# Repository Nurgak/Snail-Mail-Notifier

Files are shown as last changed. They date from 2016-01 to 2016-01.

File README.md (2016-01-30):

# Snail Mail Notifier

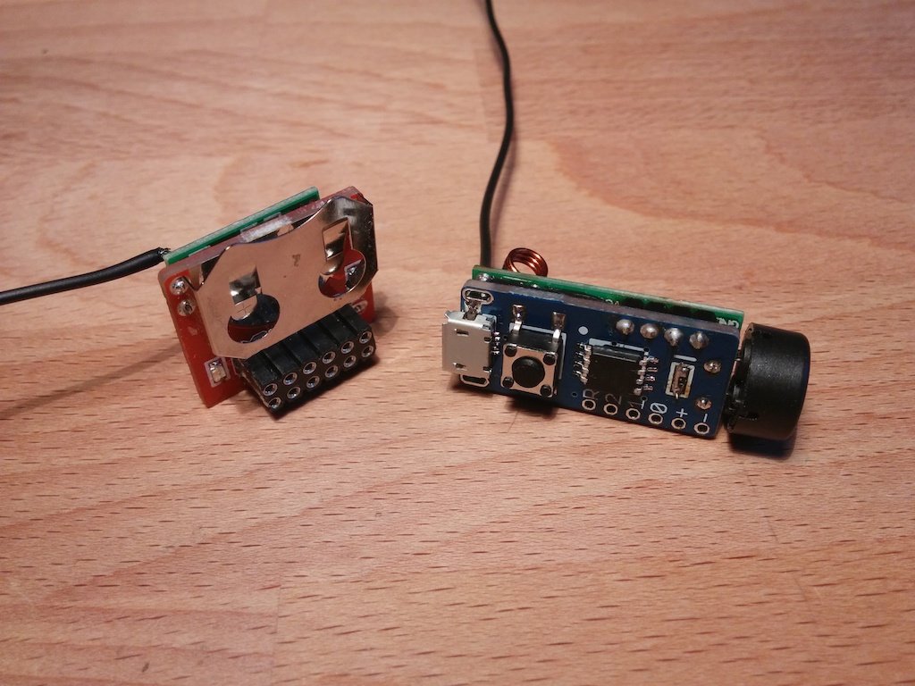
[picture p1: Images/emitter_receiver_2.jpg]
Snail Mail Notifier transmitter and receiver


The Snail Mail Notifier is a small module based on a one-way transmitter-receiver pair and [ATtiny85](http://www.atmel.com/devices/attiny85.aspx) microcontrollers, it's purpose is to inform a user of the arrival of regular mail as soon as the mailbox lid has been opened. The receiver can notify the user via a buzzer, a blinking LED or transmit data to a computer that can forward an e-mail.

[The project development is documented on Hackaday.io](https://hackaday.io/project/1954-snail-mail-notifier).

## License

The Snail Mail Notifier is published under [Creative Commons Attribution license](http://creativecommons.org/licenses/by/3.0/).



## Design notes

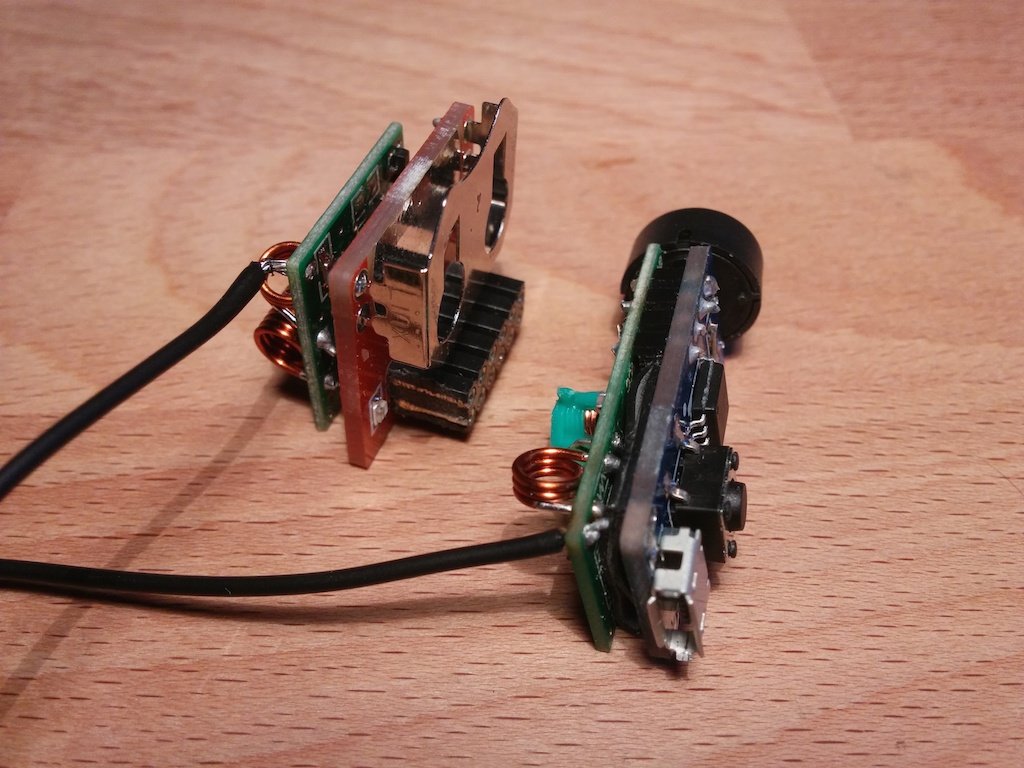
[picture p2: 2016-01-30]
Images/emitter_receiver.jpg

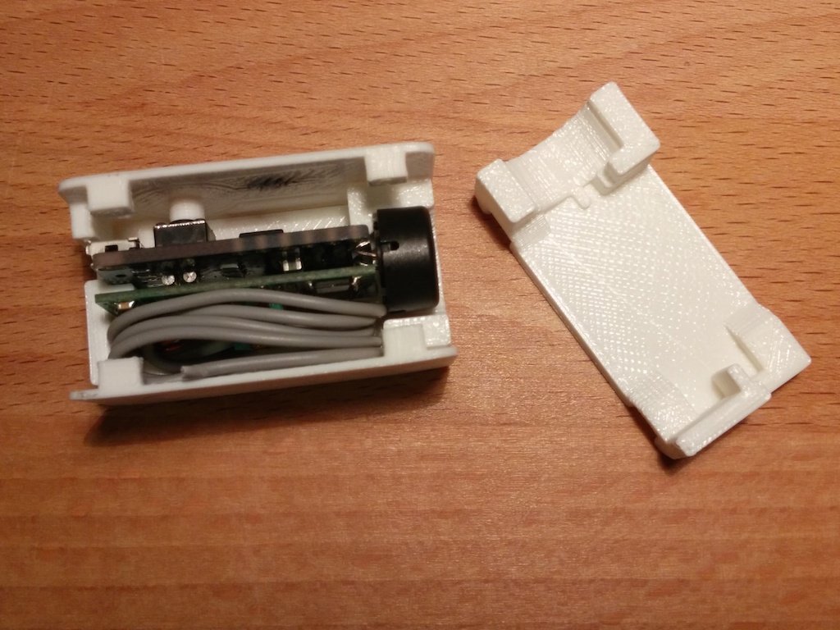
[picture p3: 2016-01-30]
Images/receiver_opened.jpg

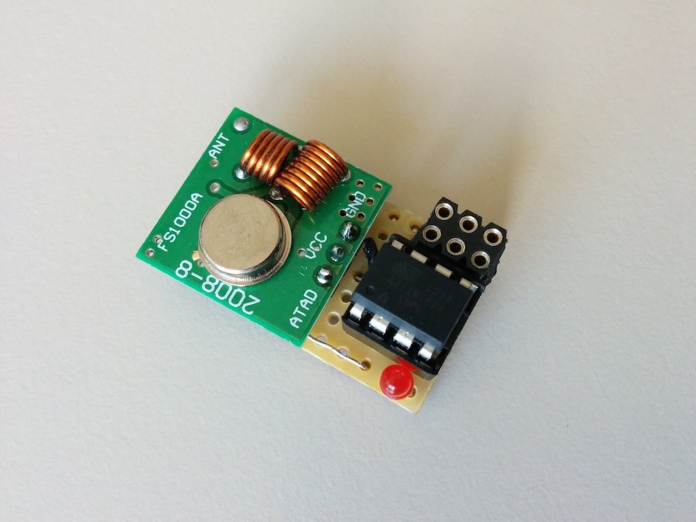
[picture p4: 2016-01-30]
Images/emitter_perfboard.jpg

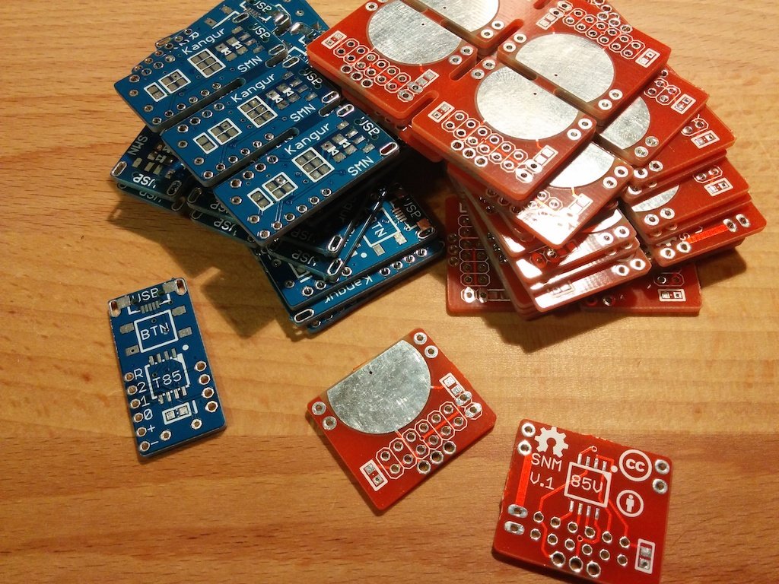
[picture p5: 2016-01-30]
Images/pcbs_panelised.jpg

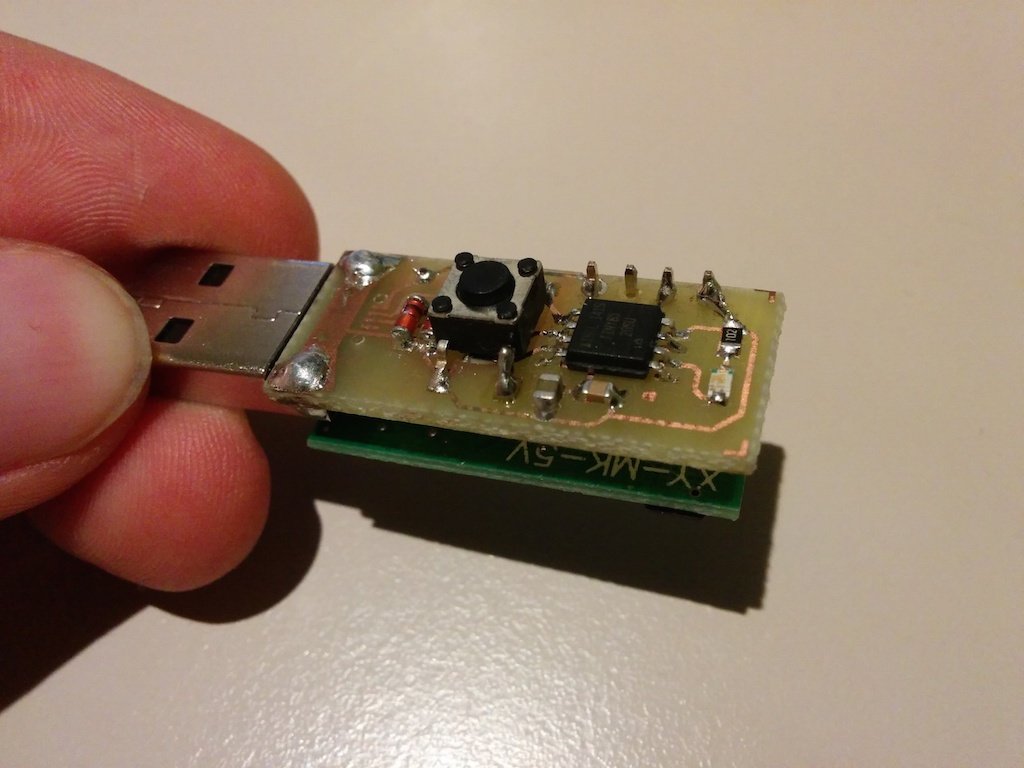
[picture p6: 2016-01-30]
Images/receiver_etched.jpg

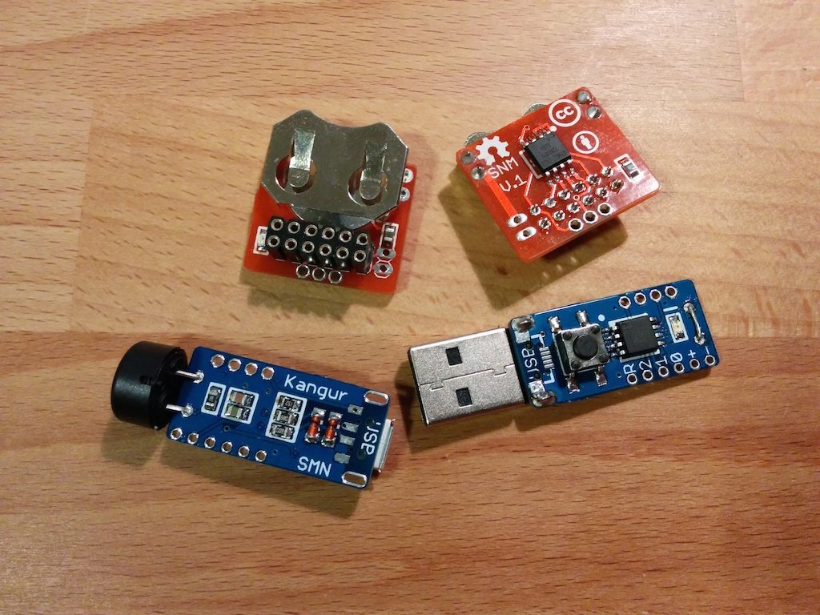
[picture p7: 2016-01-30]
Images/emitter_receiver_3.jpg

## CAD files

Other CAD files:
Hardware/Enclosure_receiver.skp

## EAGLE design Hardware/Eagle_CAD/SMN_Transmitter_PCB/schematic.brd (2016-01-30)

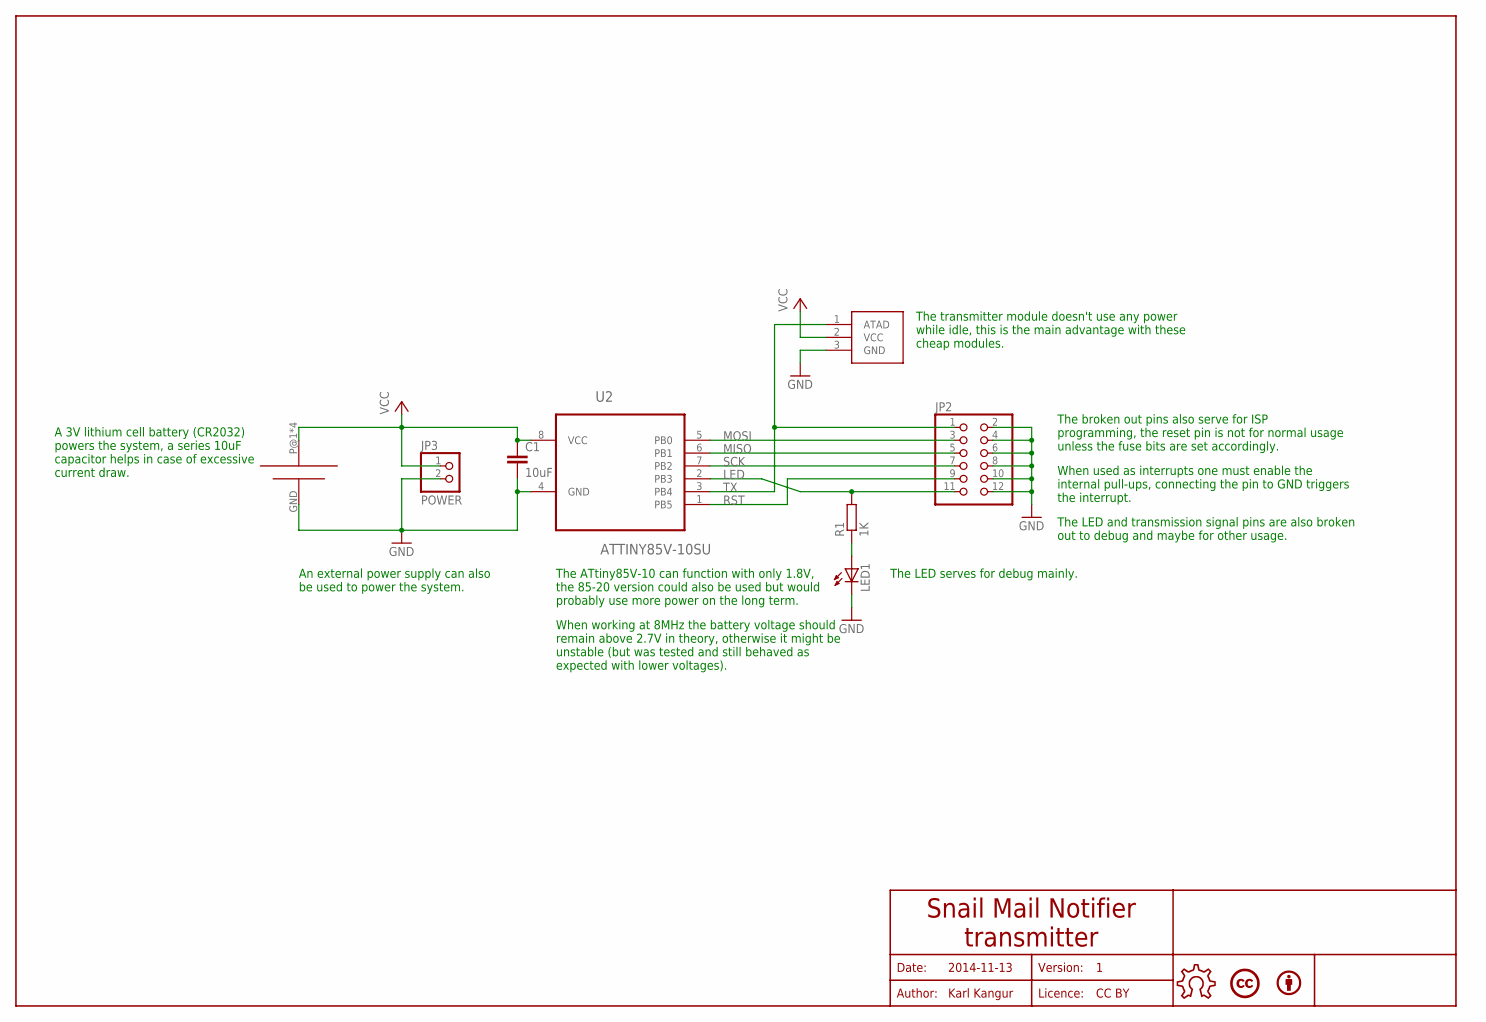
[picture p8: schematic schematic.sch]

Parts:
BY1: BYBOTTOM; BY
C1: 10uF; C0805
JP2: PINHD-2X6; 2X06
JP3: POWER; 1X02
LED1: LEDCHIPLED_0805; CHIPLED_0805
LICENCE1: LICENCECC-BOTTOM; CREATIVE-COMMONS
R1: 1K; R0805
U2: ATTINY85V-10SU; SOIC127P798X216-8N
U$1: RF_LINK_TRANSMITTER
U$2: CR2032-BATTERY-HOLDER; CR2032-BATTERY-HOLDER-PCB
U$5: OPEN-HARDWARE-LOGOBOTTOM-SMALL; OPEN-HARDWARE-BOTTOM-SMALL

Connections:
GND: C1.2, JP2.2, JP2.4, JP2.6, JP2.8, JP2.10, JP2.12, JP3.2, LED1.C, U2.4 (GND), U$1.3 (GND), U$2.GND (N)
LED: JP2.11, R1.2, U2.2 (PB3)
MISO: JP2.5, U2.6 (PB1)
MOSI: JP2.3, U2.5 (PB0)
unnamed: LED1.A, R1.1
RST: JP2.9, U2.1 (PB5)
SCK: JP2.7, U2.7 (PB2)
TX: JP2.1, U2.3 (PB4), U$1.1 (ATAD)
VCC: C1.1, JP3.1, U2.8 (VCC), U$1.2 (VCC), U$2.P@1, U$2.P@2, U$2.P@3, U$2.P@4

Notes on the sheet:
Date:
Author:
Licence:
Version:
2014-11-13
Karl Kangur
CC BY
Snail Mail Notifier transmitter
The ATtiny85V-10 can function with only 1.8V, the 85-20 version could also be used but would probably use more power on the long term.
The broken out pins also serve for ISP programming, the reset pin is not for normal usage unless the fuse bits are set accordingly.
A 3V lithium cell battery (CR2032) powers the system, a series 10uF capacitor helps in case of excessive current draw.
An external power supply can also be used to power the system.
The transmitter module doesn't use any power while idle, this is the main advantage with these cheap modules.
When used as interrupts one must enable the internal pull-ups, connecting the pin to GND triggers the interrupt.
The LED serves for debug mainly.
When working at 8MHz the battery voltage should remain above 2.7V in theory, otherwise it might be unstable (but was tested and still behaved as expected with lower voltages).
The LED and transmission signal pins are also broken out to debug and maybe for other usage.

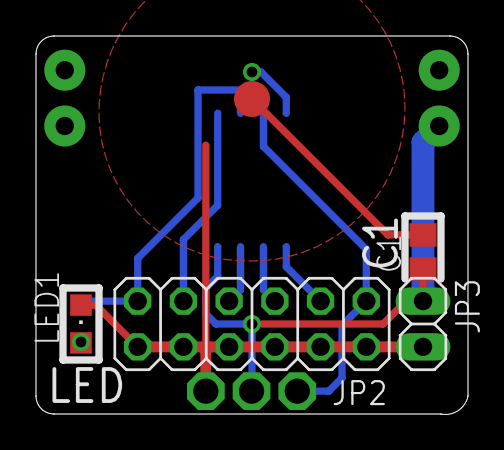
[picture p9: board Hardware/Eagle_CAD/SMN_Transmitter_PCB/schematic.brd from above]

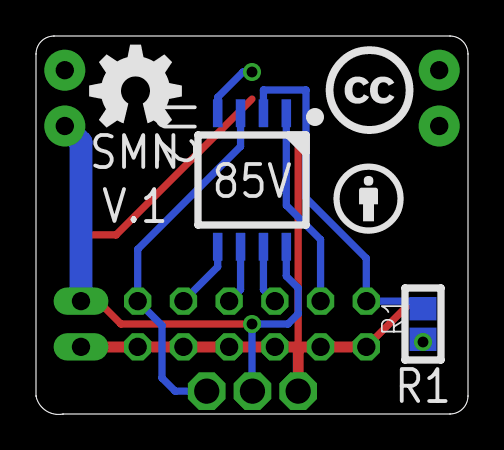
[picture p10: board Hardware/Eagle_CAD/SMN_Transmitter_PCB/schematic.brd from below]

Board: 2 copper layers, 24.0 x 21.0 mm, 11 parts (3 on the bottom side), 9 nets.

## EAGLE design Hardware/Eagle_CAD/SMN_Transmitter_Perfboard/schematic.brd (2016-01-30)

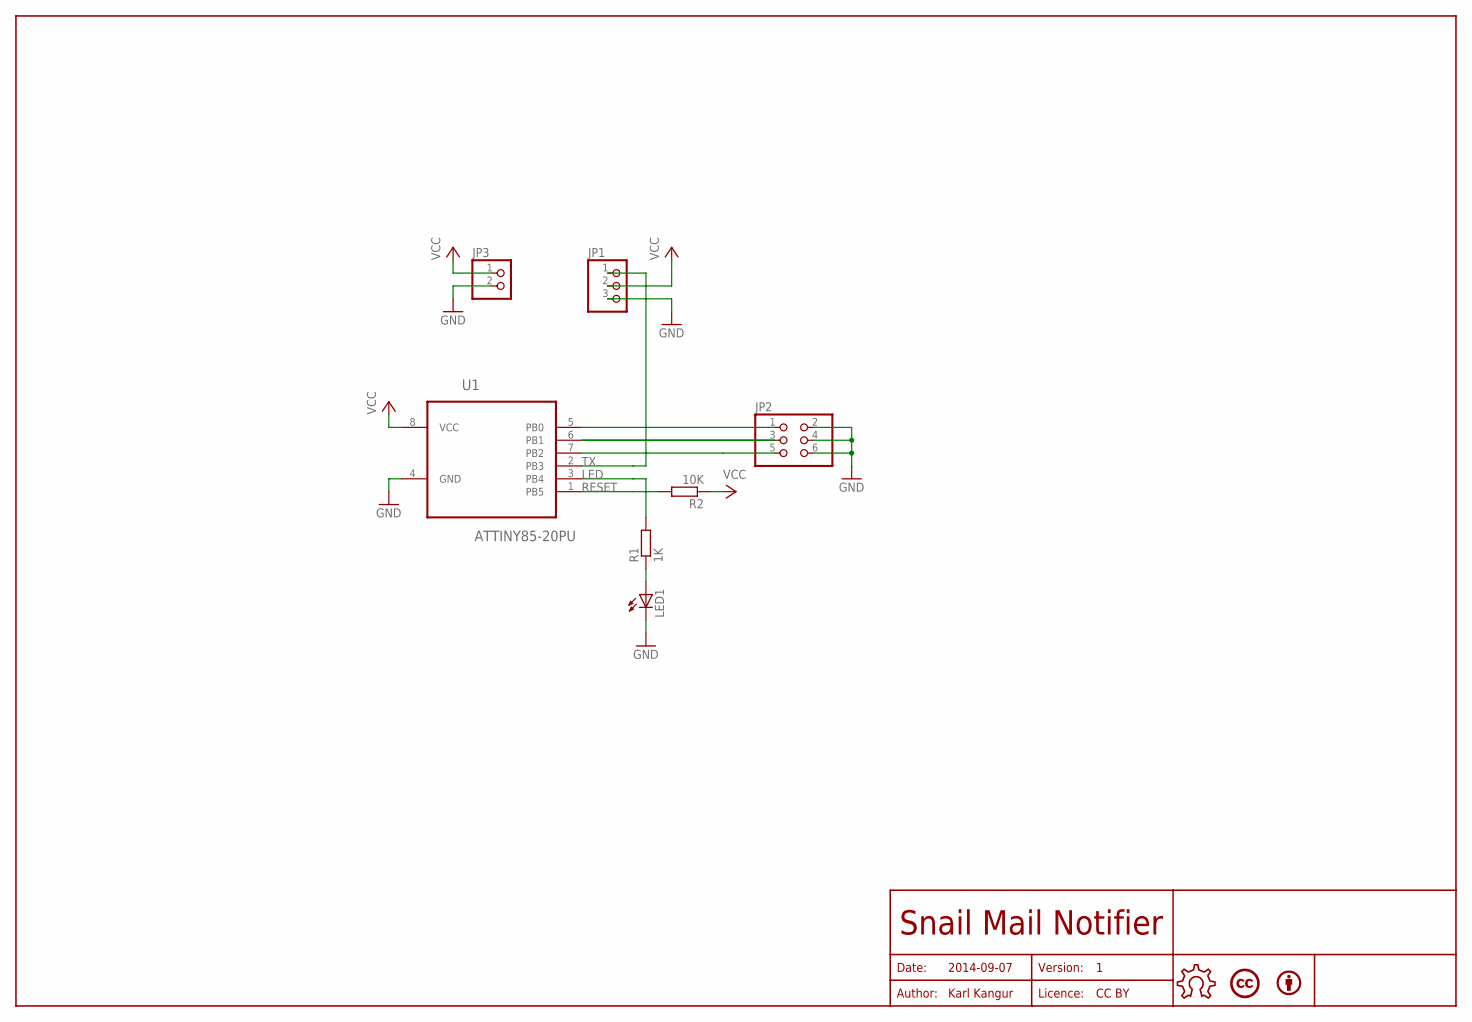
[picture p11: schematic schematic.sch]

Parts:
BY1: BYBOTTOM; BY
JP1: PINHD-1X3; 1X03
JP2: PINHD-2X3; 2X03
JP3: PINHD-1X2/90; 1X02/90
LED1: LED3MM
LICENCE1: LICENCECC-BOTTOM; CREATIVE-COMMONS
R1: 1K; R0805
R2: 10K; R0805
U1: ATTINY85-20PU; DIP254P762X533-8
U$5: OPEN-HARDWARE-LOGOBOTTOM-SMALL; OPEN-HARDWARE-BOTTOM-SMALL

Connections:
GND: JP1.3, JP2.2, JP2.4, JP2.6, JP3.2, LED1.K (C)
LED: R1.2, U1.3 (PB4)
unnamed: LED1.A, R1.1
unnamed: JP2.1, U1.5 (PB0)
unnamed: JP2.3, U1.6 (PB1)
unnamed: JP2.5, U1.7 (PB2)
RESET: R2.2, U1.1 (PB5)
TX: JP1.1, U1.2 (PB3)
VCC: JP1.2, JP3.1, R2.1, U1.8 (VCC)

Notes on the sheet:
Date:
Author:
Licence:
Version:
2014-09-07
Karl Kangur
CC BY
Snail Mail Notifier

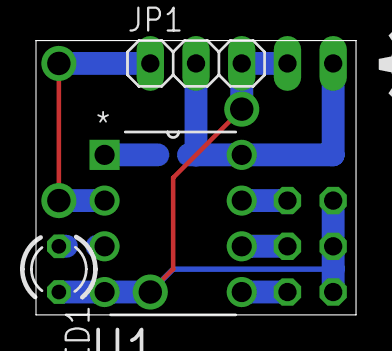
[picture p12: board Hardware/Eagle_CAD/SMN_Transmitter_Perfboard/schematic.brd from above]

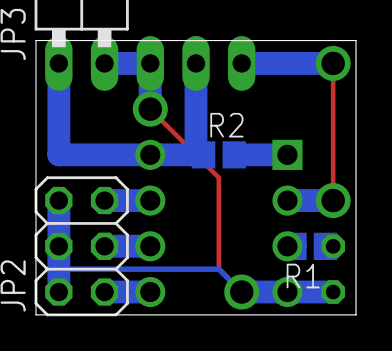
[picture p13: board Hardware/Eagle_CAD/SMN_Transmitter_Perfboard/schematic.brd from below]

Board: 2 copper layers, 17.8 x 15.2 mm, 10 parts (7 on the bottom side), 9 nets.

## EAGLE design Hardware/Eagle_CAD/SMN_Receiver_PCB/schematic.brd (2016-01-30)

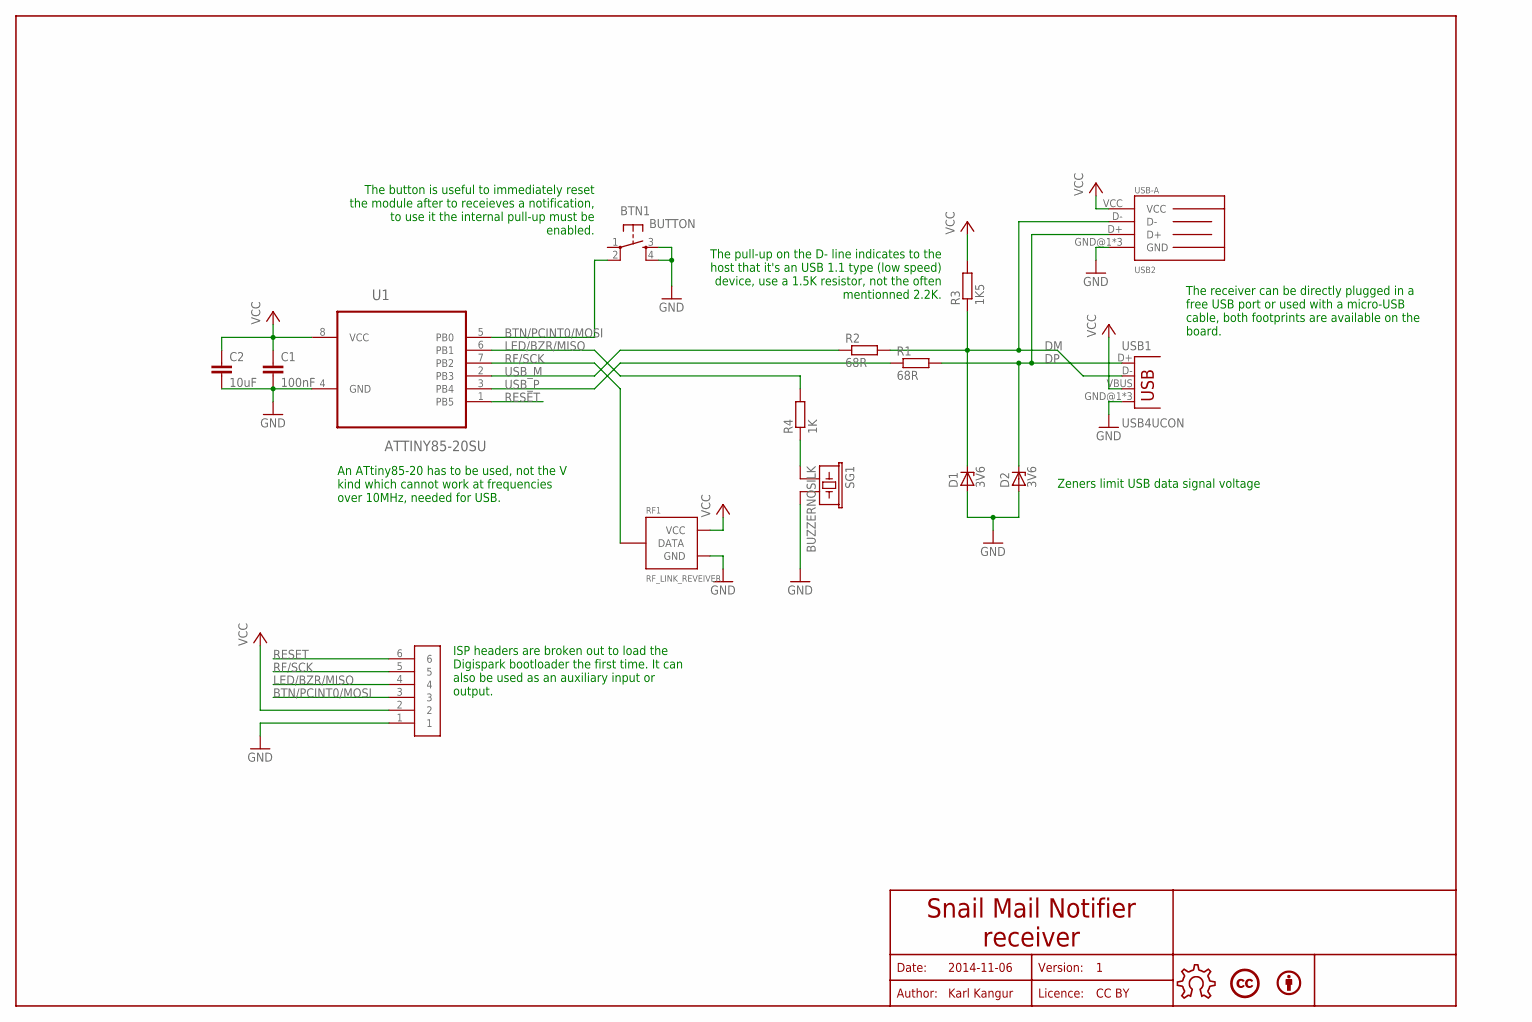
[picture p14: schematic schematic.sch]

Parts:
BTN1: BUTTON
BY1: BYBOTTOM; BY
C1: 100nF; C0805
C2: 10uF; C0805
D1, D2: 3V6; SOD80C
LICENCE1: LICENCECC-BOTTOM; CREATIVE-COMMONS
PIN1: PINS-6
R1, R2: 68R; R0805
R3: 1K5; R0805
R4: 1K; R0805
RF1: RF_LINK_REVEIVER
SG1: BUZZERNOSILK; PS1240P02BT-NOSILK
U1: ATTINY85-20SU; SOIC127P798X216-8N
U$5: OPEN-HARDWARE-LOGOBOTTOM-SMALL; OPEN-HARDWARE-BOTTOM-SMALL
USB1: USB4UCON; USB-MICROB-4UCON
USB2: USB-A

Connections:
BTN/PCINT0/MOSI: BTN1.2, PIN1.3, U1.5 (PB0)
DM: D1.C, R2.2, R3.1, USB1.D-, USB2.D-
DP: D2.C, R1.2, USB1.D+, USB2.D+
GND: BTN1.3, BTN1.4, C1.2, C2.2, D1.A, D2.A, PIN1.1, RF1.GND, SG1.P$2 (2), U1.4 (GND), USB1.GND@1 (GND), USB1.GND@4 (GND), USB1.GND@5 (GND), USB2.GND@1 (GND), USB2.GND@2 (GND), USB2.GND@3 (GND)
LED/BZR/MISO: PIN1.4, R4.2, U1.6 (PB1)
unnamed: R4.1, SG1.P$1 (1)
RESET: PIN1.6, U1.1 (PB5)
RF/SCK: PIN1.5, RF1.DATA@1 (DATA), RF1.DATA@2 (DATA), U1.7 (PB2)
USB_M: R2.1, U1.2 (PB3)
USB_P: R1.1, U1.3 (PB4)
VCC: C1.1, C2.1, PIN1.2, R3.2, RF1.VCC, U1.8 (VCC), USB1.VBUS, USB2.VCC

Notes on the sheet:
Date:
Author:
Licence:
Version:
2014-11-06
Karl Kangur
CC BY
Snail Mail Notifier receiver
The receiver can be directly plugged in a free USB port or used with a micro-USB cable, both footprints are available on the board.
Zeners limit USB data signal voltage
The pull-up on the D- line indicates to the host that it's an USB 1.1 type (low speed) device, use a 1.5K resistor, not the often mentionned 2.2K.
The button is useful to immediately reset the module after to receieves a notification, to use it the internal pull-up must be enabled.
An ATtiny85-20 has to be used, not the V kind which cannot work at frequencies over 10MHz, needed for USB.
ISP headers are broken out to load the Digispark bootloader the first time. It can also be used as an auxiliary input or output.

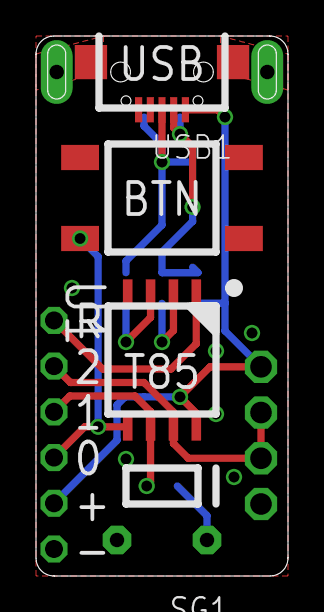
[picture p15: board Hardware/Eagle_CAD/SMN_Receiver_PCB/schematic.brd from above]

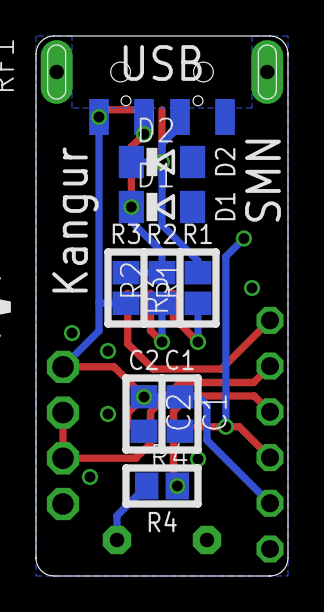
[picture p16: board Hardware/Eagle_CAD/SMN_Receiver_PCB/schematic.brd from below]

Board: 2 copper layers, 14.0 x 30.0 mm, 18 parts (12 on the bottom side), 11 nets.

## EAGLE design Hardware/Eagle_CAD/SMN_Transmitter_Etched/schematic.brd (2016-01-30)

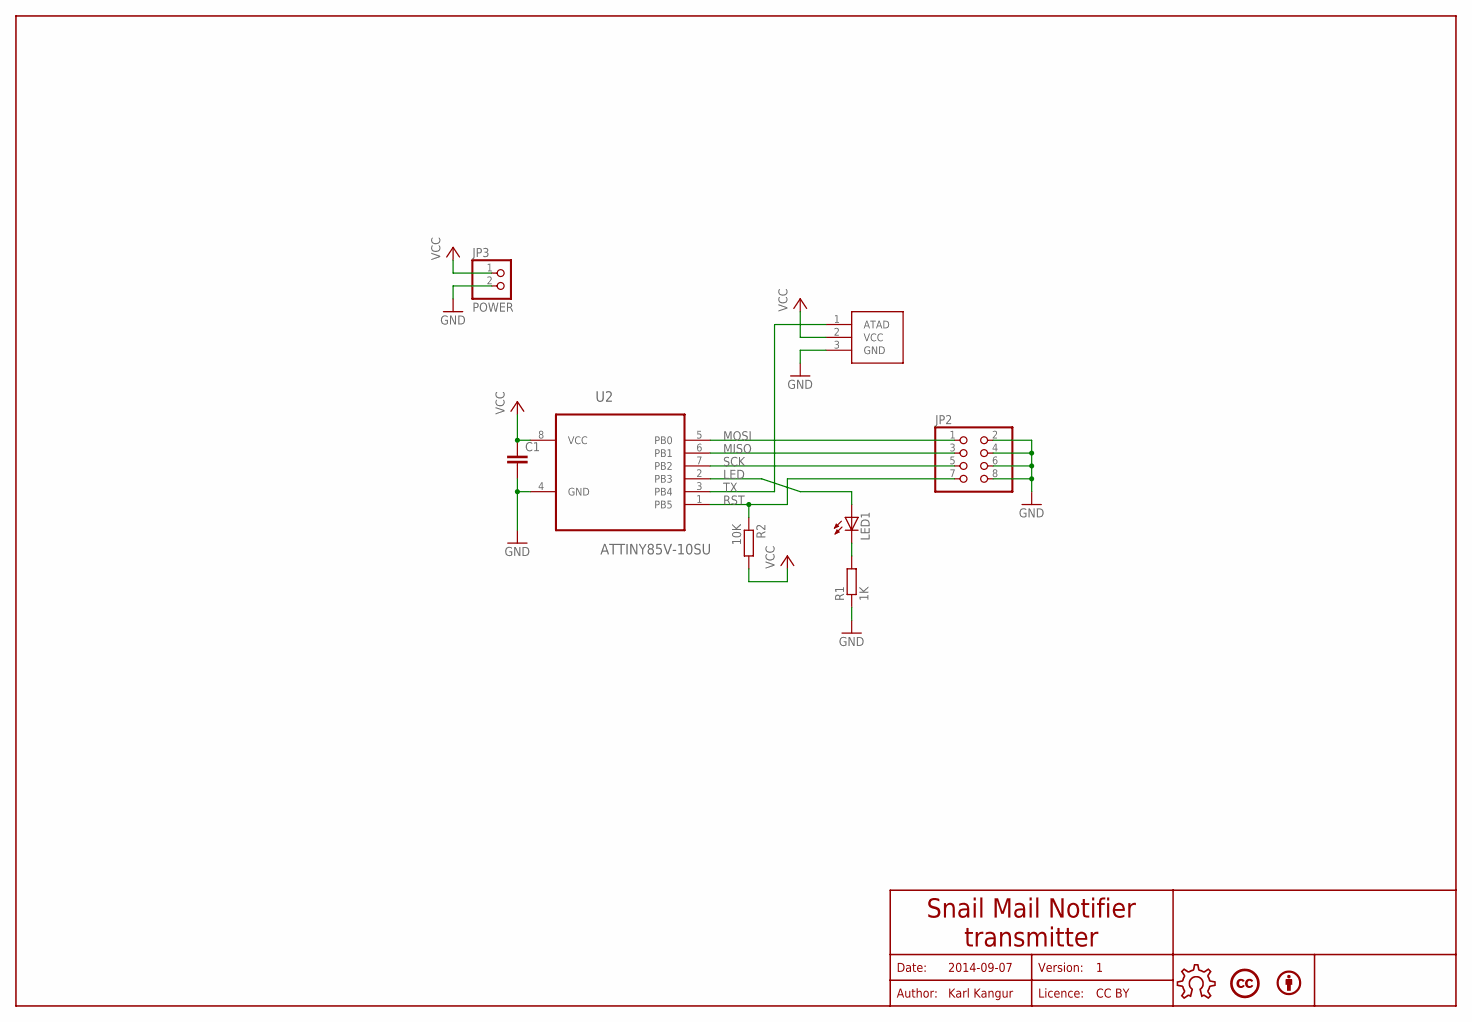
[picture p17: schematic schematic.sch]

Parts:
BY1: BYBOTTOM; BY
C1: C-EUC0805; C0805
JP2: PINHD-2X4; 2X04
JP3: POWER; 1X02
LED1: LED3MM
LICENCE1: LICENCECC-BOTTOM; CREATIVE-COMMONS
R1: 1K; R0805
R2: 10K; R0805
U2: ATTINY85V-10SU; SOIC127P798X216-8N
U$1: RF_LINK_TRANSMITTER
U$5: OPEN-HARDWARE-LOGOBOTTOM-SMALL; OPEN-HARDWARE-BOTTOM-SMALL

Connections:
GND: C1.2, JP2.2, JP2.4, JP2.6, JP2.8, JP3.2, R1.1, U2.4 (GND), U$1.3 (GND)
LED: LED1.A, U2.2 (PB3)
MISO: JP2.3, U2.6 (PB1)
MOSI: JP2.1, U2.5 (PB0)
unnamed: LED1.K (C), R1.2
RST: JP2.7, R2.1, U2.1 (PB5)
SCK: JP2.5, U2.7 (PB2)
TX: U2.3 (PB4), U$1.1 (ATAD)
VCC: C1.1, JP3.1, R2.2, U2.8 (VCC), U$1.2 (VCC)

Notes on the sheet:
Date:
Author:
Licence:
Version:
2014-09-07
Karl Kangur
CC BY
Snail Mail Notifier transmitter

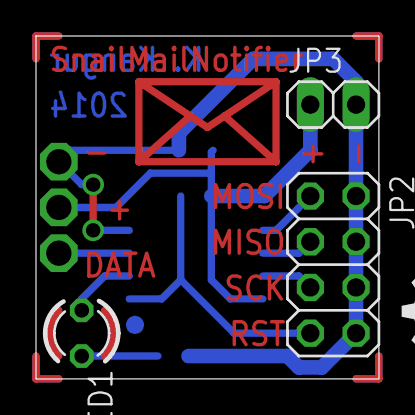
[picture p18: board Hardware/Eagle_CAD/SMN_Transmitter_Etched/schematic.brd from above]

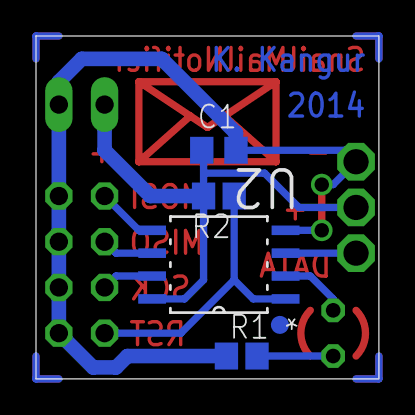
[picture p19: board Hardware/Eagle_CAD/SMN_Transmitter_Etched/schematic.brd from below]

Board: 2 copper layers, 19.1 x 19.1 mm, 11 parts (8 on the bottom side), 9 nets.

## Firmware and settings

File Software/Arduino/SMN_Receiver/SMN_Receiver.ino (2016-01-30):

/***************************************************************************************
 *
 * Title:       Snail Mail Notifier - Receiver
 * File:        SMN_Receiver.ino
 * Version:     v0.1
 * Date:        2016-01-24
 * Author:      Karl Kangur <karl.kangur@gmail.com>
 * Licence:     CC-BY
 * Website:     https://github.com/Nurgak/Snail-Mail-Notifier
 * Development: https://hackaday.io/project/1954-snail-mail-notifier
 *
 ***************************************************************************************/
#define F_CPU 16500000UL

#include <avr/wdt.h>
#include <VirtualWire.h> // This version of VirtualWire comes with Digispark libraries and has been modified to work with Digispark
#include "DigiKeyboard.h"
#include "pitch.h"
#include "sound.h"

// ATMEL ATTINY85 / ARDUINO / DIGISPARK pinout
//
//                       +-\/-+
//  RST, Ain0 (D5) PB5  1|    |8  Vcc
// USB-, Ain3 (D3) PB3  2|    |7  PB2 (D2) Ain1, PCINT2, INT0, RX
// USB+, Ain2 (D4) PB4  3|    |6  PB1 (D1) PWM1, PCINT1, BUZZER
//                 GND  4|    |5  PB0 (D0) PWM0, PCINT0, BUTTON
//                       +----+

#define KEY_STROKE        KEY_L // Key stroke sent to the computer when a message is receieved
#define MOD_KEYS          MOD_CONTROL_LEFT | MOD_ALT_LEFT | MOD_GUI_LEFT  // Modifier keys such as Ctrl, Alt, Option...
#define SLEEP_MULTIPLIER  450  // Watchdog resets the system when it has been triggered after 450*8s = 3600s = 1h, maximum is 0xfffe
#define BITRATE           200  // Bitrate at which the emitter sends data to the receiver, must be the same on emitter and receiver
#define PIN_BUTTON        0    // Pin definition for button
#define PIN_BUZZER        1    // Pin definition for buzzer
#define PIN_RX            2    // Pin definition for receiver ping
// Pins 3 and 4 are reserved for USB data lines, defined in Digispark libraries

static volatile boolean mail = false; // Volatile as called from within an interrupt vector (resetSystem())
static volatile boolean buttonBusy = false;
static volatile melodyPlay song = {0, STOP, 0, 0, 0, 0}; // Struct to track sound playing

void setup()
{
  // Switch ADC off as it is not needed
  ADCSRA &= ~_BV(ADEN);
    
  // Shut down unused peripherals (USI and ADC)
  PRR |= _BV(PRUSI) | _BV(PRADC);
  
  // Enable button pull-up
  PORTB |= _BV(PIN_BUTTON);
  
  // Receiver initialisation
  vw_set_rx_pin(PIN_RX);
  vw_setup(BITRATE);
  vw_rx_start();
  
  // Watchdog interrupt to reset the system after an hour
  WDTCR = _BV(WDP3) | _BV(WDP0); // Set watchdog timeout to 8s, do not enable yet
}

// Watchdog timeout interrupt vector called every 8s, non blocking since low priority
ISR(WDT_vect, ISR_NOBLOCK)
{
  static uint16_t sleepTimer;

  // Trick to make the countdown internal to the interrupt vector
  if(sleepTimer == 0xffff)
  {
    sleepTimer = SLEEP_MULTIPLIER;
  }
  else
  {
    sleepTimer--;
  }
  
  if(!sleepTimer)
  {
    sleepTimer = 0xffff;
    
    // Disable watchdog, reset system
    WDTCR &= ~_BV(WDIE);
    resetSystem();
  }
}

// Interrupt vector for buzzer sounds, non blocking since low priority
ISR(TIMER0_OVF_vect, ISR_NOBLOCK)
{
  if(song.action == STOP)
  {
    return;
  }
  
  if(song.calls > 0)
  {
    // Decrement call count
    song.calls--;
    // Toggle pin value to make some sound
    PORTB ^= _BV(PIN_BUZZER);
  }
  else if(song.pause > 0)
  {
    // Decrement pause count while not toggling the buzzer pin
    song.pause--;
  }
  else
  {
    // The melody is finished, stop
    if(song.noteCounter == -1)
    {
      song.noteCounter = 0;
      notification(STOP);
      
      // Allow user to push the button again
      buttonBusy = false;
      
      return;
    }
    
    // Evaluate timeout value for the given sound freqency, one has to use the timeout interrupt vector as the overflow won't work
    // The timeout vector is always called at TOP = 0xff in CTC mode so simply set an offset to the timer 0 counter register: TCNT0
    // TCNT0 = 0xff - (16.5MHz / 1024 / 2 / frequency)
    song.nextCall = 0xff - ((F_CPU >> 11) / song.reference->notes[song.noteCounter].pitch);
    
    // If the frequency of the current sound is the same as the next one insert a 5ms pause at the end of the note duration to define the notes better
    if(song.noteCounter < song.reference->length - 2 && song.reference->notes[song.noteCounter].pitch == song.reference->notes[song.noteCounter + 1].pitch)
    {
      // The casting is necessary or it won't behave as expected
      // The division is by 500 instead of 1000 because the pin is toggeled instead of making a full period per interrupt call, so there are twice the number of cycles
      song.calls = ((uint32_t) song.reference->notes[song.noteCounter].pitch * (song.reference->notes[song.noteCounter].duration - 5)) / 500;
      // Insert a 5ms pause at the end of the sound
      song.pause = (song.reference->notes[song.noteCounter].pitch * 5) / 500;
    }
    else
    {
      // Evaluate call count for given frequency
      song.calls = ((uint32_t) song.reference->notes[song.noteCounter].pitch * song.reference->notes[song.noteCounter].duration) / 500;
    }
    
    if(song.noteCounter < song.reference->length - 1)
    {
      // Evaluate calls for the next frequency
      song.noteCounter++;
    }
    else
    {
      // End of the song, stop
      song.noteCounter = -1;
    }
  }
  
  // Set the counter register to a set value so it would trigger this interrupt next time
  TCNT0 = song.nextCall;
}

void loop()
{
  // Buffer for the received message
  static uint8_t buf[5] = {0};
  static uint8_t buflen = sizeof(buf) / sizeof(buf[0]);

  // Received data variables
  static uint8_t address = 0;
  static uint16_t voltage = 0;
  static uint8_t temperature = 0;
  static uint8_t data = 0; // Dummy data, should be 0x55 by default

  // The receiver can only receieve a message when not playing a notification as they use the same timer
  if(song.action == STOP && !mail && vw_get_message(buf, &buflen))
  {
    // Fill the values
    address = buf[0];
    voltage = (buf[1] << 8) | buf[2];
    temperature = buf[3];
    data = buf[4];

    // Send the key stroke to the computer
    DigiKeyboard.sendKeyStroke(KEY_STROKE, MOD_KEYS);
    
    // Toggle mail flag
    mail = true;

    // Enable watchdog timeout (WDT_vect) interrupt
    wdt_reset();
    WDTCR |= _BV(WDIE);
    
    selectMelody(&melodyNewMail);
  }
  
  // Button was pressed, cannot use the interrupt vector as the DigiKeyboard library needs it, so poll instead
  if(!(PINB & _BV(PIN_BUTTON)) && !buttonBusy)
  {
    button();
  }
  
  // Wait 1ms and fill the time with USB polling to indicate to the computer that the device has not disappeared
  DigiKeyboard.delay(1);
}

void button()
{
  // The user can reset the system by pushing on the button
  resetSystem();
  
  // The user could be holding the button down, prevent calling this multiple times
  buttonBusy = true;
  selectMelody(&melodyButtonPush);
}

void selectMelody(const melody * _melody)
{
  // Select the melody to play by setting the references to the sound and its length
  song.reference = (melody *)_melody;
    
  // Enable notification so the buzzer would play
  notification(PLAY);
}

// Setup the buzzer to notify user of arrived mail
void notification(operation action)
{
  // Save timer 0 configuration, since the receiver uses the same timer as the buzzer
  static uint8_t temp_TCCR0A = TCCR0A;
  static uint8_t temp_TCCR0B = TCCR0B;
  static uint8_t temp_OCR0A = OCR0A;
  static uint8_t temp_TIMSK = TIMSK;
  
  if(action == PLAY)
  {
    // Set buzzer pin to output
    DDRB |= _BV(PIN_BUZZER);
    
    // Reset sound generation variables
    song.calls = 0;
    song.pause = 0;
    song.nextCall = 0;
    song.noteCounter = 0;
    
    TCCR0A = _BV(WGM01); // CTC mode
    OCR0A = 0xff; // Count up to 0xff to trigger the overflow interrupt vector
    TIMSK |= _BV(TOIE0); // Enable the overflow (TIMER0_OVF_vect) interrupt vector to change frequency
    TCCR0B = _BV(CS02) | _BV(CS00); // Prescaler = 1024
  }
  else
  {
    // Restore timer 0 configuration
    TCCR0A = temp_TCCR0A;
    TCCR0B = temp_TCCR0B;
    OCR0A = temp_OCR0A;
    TIMSK = temp_TIMSK;
    
    // Set buzzer pin off and to input mode
    PORTB &= ~_BV(PIN_BUZZER);
    DDRB &= ~_BV(PIN_BUZZER);
  }
  
  song.action = action;
}

void resetSystem()
{
  // Disable watchdog interrupt for automatic reset (not actual MCU reset, only program reset)
  WDTCR |= _BV(WDIE);
  
  // Turn off the notification
  notification(STOP);
  
  // Remove mail flag
  mail = false;
}

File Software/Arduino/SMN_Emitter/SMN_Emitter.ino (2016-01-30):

 /***************************************************************************************
 *
 * Title:       Snail Mail Notifier - Emitter
 * File:        SMN_Emitter.ino
 * Version:     v0.1
 * Date:        2016-01-24
 * Author:      Karl Kangur <karl.kangur@gmail.com>
 * Licence:     CC-BY
 * Website:     https://github.com/Nurgak/Snail-Mail-Notifier
 * Development: https://hackaday.io/project/1954-snail-mail-notifier
 *
 ***************************************************************************************/
#include <avr/sleep.h>
#include <avr/wdt.h>
// VirtualWire downloaded from http://www.airspayce.com/mikem/arduino/VirtualWire/ and renamed to VirtualWire_emitter,
// needed so it would not conflict with the receiver VirtualWire library
#include <VirtualWire_emitter.h>

#define ADDRESS           0xf1  // This is arbitrary, might be useful when multiple emitters transmit to one receiver
#define BITRATE           200   // Lower bitrate allows communication over greater distances
#define SLEEP_MULTIPLIER  1     // Time the microcontroller sleeps after sending a message, multiples of 8 seconds, ex: 8*8=64 seconds
#define TEMP_OFFSET       273   // Temperature offset when reading internal temperature sensor
#define SEND_TIMES        3     // How many times the message is sent every time, higher number is more robust
#define PIN_LED           3     // Definition for the LED pin
#define PIN_TX            4     // Definition for the transmission pin

void setup()
{
  // Disable interrupts for setup, just in case
  cli();
  
  // Set the sleep mode that is going to be used, lowest possible is SLEEP_MODE_PWR_DOWN
  set_sleep_mode(SLEEP_MODE_PWR_DOWN);
  
  // Setup the transmission parameters
  vw_setup(BITRATE);
  vw_set_tx_pin(PIN_TX);
  
  // Power Reduction Register (datasheet p. 38)
  // Turn everything off: Timer1, USI and ADC clock signals stopped.
  //PRR = (1 << PRTIM1) | (1 << PRUSI) | (1 << PRADC);
  // DO NOT USE!!!
  // For some reason the current goes up 200uA when disabling these features, so do not disable them.
  // This is probably due to the state of the peripheral being frozen while it still somehow consumes power.
  
  // Switch ADC converter off to save power
  ADCSRA &= ~_BV(ADEN);
  
  // Enable pull-up resistors on pins PB2, PB1 and PB0
  PORTB |= _BV(PORTB2) | _BV(PORTB1) | _BV(PORTB0);
  
  // Enable pin change interrupts on pins PB2, PB1 and PB0, they all call the same interrupt vector: PCINT0_vect
  PCMSK |= _BV(PCINT2) | _BV(PCINT1) | _BV(PCINT0);
  // PB2 has technically another way to be interrupted (INT0), allowing for a different interrupt vector,
  // but it reqires system clock which is not available since the microcontroller is going to sleep
  
  // Enable all interrupts
  sei();
}

void loop()
{
  static uint8_t sleep_counter;

  // Enable the pin change interrupts
  GIMSK |= _BV(PCIE);
  // This needs to be called twice the second time it is called, because the PCIE bit is not set, this is a very strange issue...
  GIMSK |= _BV(PCIE);
  
  // Put the microcontroller to sleep to conserve power
  sleep();
  // The microcontroller has been waked up by a pin change interrupt...
  
  // Send the message to the receiver
  sendMessage();
  
  // Configure the watchdog to timeout after 8 seconds
  WDTCR = _BV(WDP3) | _BV(WDP0);

  // Reset the sleep counter
  sleep_counter = SLEEP_MULTIPLIER;
  
  // Reset the watchdog timer, it is an asychronous task and might be about to timeout
  wdt_reset();

  while(sleep_counter--)
  {
    // Enable the watchdog interrupt, it will wake up the microcontroller in 8 seconds
    WDTCR |= _BV(WDIE);
    // Power down the microcontroller
    sleep();
  }
}

void sleep()
{
  sleep_enable();
  sleep_mode();
  // System sleeps here
  sleep_disable();
}

// Pin change interrupt vector
ISR(PCINT0_vect)
{
  // Turn off the pin change interrupts so it will not be called over and over
  GIMSK &= ~_BV(PCIE);
}

// Watchdog interrupt vector
ISR(WDT_vect)
{
  // Disable the watchdog interrupt
  WDTCR &= ~_BV(WDIE);
}

void sendMessage()
{
  // Message buffer
  uint8_t msg[5] = {0};
  uint8_t retries_counter = SEND_TIMES;

  // Switch analog-to-digital (ADC) on
  ADCSRA |= _BV(ADEN);
  
  // Get the battery voltage and temperature values
  uint16_t voltage = readVcc();
  int8_t temperature = readTemp();
  
  // Switch ADC off to conserve power
  ADCSRA &= ~_BV(ADEN);

  // Build the message packet
  // Protocol: 1 byte for address, 2 bytes for voltage level, 1 byte for temperature, 1 byte for data
  msg[0] = ADDRESS;
  msg[1] = voltage >> 8;
  msg[2] = voltage & 0xff;
  msg[3] = temperature;
  msg[4] = 0x55; // Dummy data, can be used for checksums or whatever

  // Configure the watchdog for 1 second call
  WDTCR = _BV(WDP2) | _BV(WDP1);
  
  // Set LED pin as output
  DDRB |= _BV(PIN_LED);

  // Send the message multiple times to make sure the receiver catches it
  while(retries_counter--)
  {    
    // Turn LED on
    PORTB |= _BV(PIN_LED);

    // Actually send the message to the receiver
    vw_send(msg, sizeof(msg) / sizeof(msg[0]));
    vw_wait_tx();

    // Turn LED off
    PORTB &= ~_BV(PIN_LED);

    // Skip the last wait period
    if(!retries_counter)
    {
      break;
    }
    
    // Reset the watchdog timer right before enabling it
    wdt_reset();
    // Enable the watchdog interrupt (not watchdog timer)
    WDTCR |= _BV(WDIE);
    // Turn off the microcontroller for 1 second
    sleep();
  }
  
  // Set LED port as input
  DDRB &= ~_BV(PIN_LED);
}

// Helper function to read battery voltage, return value in millivolts
uint16_t readVcc()
{  
  // Read bandgap reference voltage (1.1V) with reference at Vcc (?V)
  ADMUX = _BV(MUX3) | _BV(MUX2);
  
  // Wait for voltage reference reference to settle, 3ms is minimum
  _delay_ms(5);
  
  // Convert analog to digital twice (first value is unreliable)
  ADCSRA |= _BV(ADSC);
  while(bit_is_set(ADCSRA,ADSC));
  ADCSRA |= _BV(ADSC);
  while(bit_is_set(ADCSRA,ADSC));

  // Convert the value to millivolts
  return 1126400L / ADC;
}

// Helper function to read the internal temperature sensor
int8_t readTemp()
{
  int8_t i;
  uint16_t average = 0;
  
  // Read internal temperature sensor value using the bandgap reference (1.1V)
  ADMUX = _BV(REFS1) | _BV(MUX3) | _BV(MUX2) | _BV(MUX1) | _BV(MUX0);
  
  // Wait for the voltage reference to settle, 3ms is minimum
  _delay_ms(5);
  
  // Convert and dump the first value as it is not guaranteed to be correct
  ADCSRA |= _BV(ADSC);
  while(bit_is_set(ADCSRA, ADSC));
  
  // Make an average over 8 readings
  for(i = 0; i < 8; i++)
  {
    // Start the analog-to-digital (ADC) converstion
    ADCSRA |= _BV(ADSC);
    // Wait for the ADC converstion to finish
    while(bit_is_set(ADCSRA, ADSC));
    average += ADC;
  }
  
  // Divide by 8 and remove offset
  return (average >> 3) - TEMP_OFFSET;
}
